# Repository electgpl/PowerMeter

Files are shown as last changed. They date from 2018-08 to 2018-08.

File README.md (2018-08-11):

# Power Meter v1 

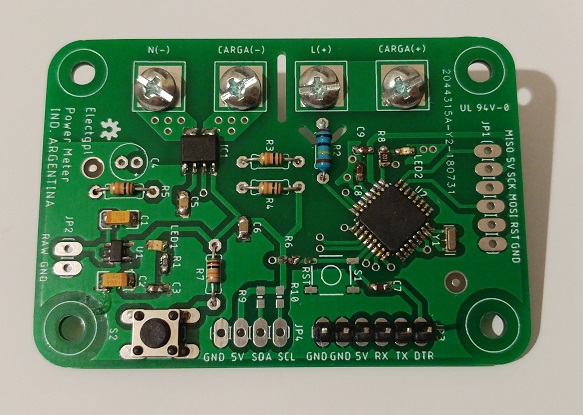
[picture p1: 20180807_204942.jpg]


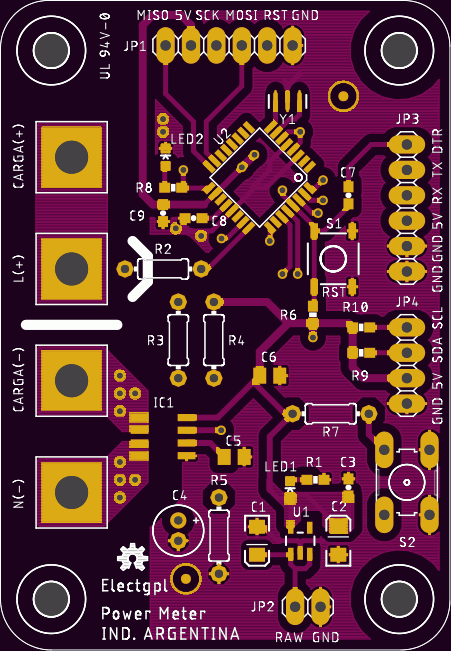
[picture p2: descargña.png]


Este es un medidor de potencia continua y alterna diseñado en base al microcontrolador AVR linea MEGA compatible ArduinoIDE.

  - Core AVR - **ARDUINO PRO MINI 5V**
  - Bootloader UART Arduino Compatible
  - ISP Compatible
  - Serial Terminal/Debug
  - Puerto para LCD I2C
  - Medidor de corriente ACS712 (Compatible 5, 20 y 30A) 
  - Medidor de Tensión **Directo** con atenuación resistiva y montado sobre 2.5V (Cero)
  - Fuente de alimentación integrada

## Lenguajes Compatibles

  - C
  - C++
  - Basic
  - Ensamblador
  - Ladder
  - y mas...
  
## Diseño y Desarrollo

> Diseñado en dos capas con SMD y THT
> Los componentes SMD son extraídos directamente de una placa Arduino Pro Mini 5V y Modulo ACS712
> Los componentes THT se adquieren con facilidad en los comercios.
>                           
> PCB creado en [JLCPCB].
> Diseño realizado en [Eagle].

### Instalación

Todos los archivos se encuentran disponibles en este repositorio, diagramas, pcb, etc...

### Pendientes

 - Código para el medidor de continua para la incorporación en fuentes de alimentación.
 - Mejoras en la aislación de seguridad eléctrica

License
----

MIT

**Free Software, Hell Yeah!**

[JLCPCB]: <https://jlcpcb.com/>
[Eagle]: <https://www.autodesk.com/products/eagle/overview>

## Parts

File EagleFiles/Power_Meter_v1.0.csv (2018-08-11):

Qty | Value | Device | Package | Parts | Description | MF | MPN | OC_FARNELL | OC_NEWARK | SPICEPREFIX
1 |  | 10-XX | B3F-10XX | S2 | OMRON SWITCH |  | B3F-1000 | 176432 | 36M3542
1 |  | PINHD-1X2 | 1X02 | JP2 | PIN HEADER
1 |  | PINHD-1X4 | 1X04 | JP4 | PIN HEADER
2 |  | PINHD-1X6 | 1X06 | JP1, JP3 | PIN HEADER
2 |  | RESISTOR0603-RES | 0603-RES | R9, R10 | Resistor
4 | 0.1uF | CAP0603-CAP | 0603-CAP | C3, C7, C8, C9 | Capacitor
1 | 100n | C-EUC0805K | C0805K | C6 | CAPACITOR, European symbol |  |  |  |  | C
2 | 10K | RESISTOR0603-RES | 0603-RES | R1, R6 | Resistor
4 | 10k | R-US_0204/7 | 0204/7 | R3, R4, R5, R7 | RESISTOR, American symbol |  |  |  |  | R
2 | 10uF | CAP_POL1206 | EIA3216 | C1, C2 | Capacitor Polarized
1 | 1M | R-US_0204/7 | 0204/7 | R2 | RESISTOR, American symbol |  |  |  |  | R
1 | 1n | C-EUC0805K | C0805K | C5 | CAPACITOR, European symbol |  |  |  |  | C
1 | 1u | CPOL-EUE2-5 | E2-5 | C4 | POLARIZED CAPACITOR, European symbol |  |  |  |  | C
1 | 330 | RESISTOR0603-RES | 0603-RES | R8 | Resistor
1 | 8/16/20MHz | RESONATOR1:1 | RESONATOR-SMD-1:1 | Y1 | Resonator
1 | ACS712 | ACS712 | SO08 | IC1
1 | ATMEGA328 | ATMEGA168 | TQFP32-08 | U2
2 | FIDUCIAL1X2.5 | FIDUCIAL1X2.5 | FIDUCIAL-1X2.5 | JP5, JP6 | Fiducial Alignment Points
1 | Green | LED | 0603-LED-ALT1 | LED2 | LEDs
1 | MIC5205 | V_REG_LDOSMD | SOT23-5 | U1 | Voltage Regulator LDO
4 | MOUNT-PAD-SQUARE3.3 | MOUNT-PAD-SQUARE3.3 | 3,3-PAD-SQUARE | H1, H2, H3, H4 | MOUNTING PAD, square
1 | OSHW-LOGOS | OSHW-LOGOS | OSHW-LOGO-S | U$5 | Open Source Hardware Logo This logo indicates the piece of hardware it is found on incorporates a OSHW license and/or adheres to the definition of open source hardware found here: http://freedomdefined.org/OSHW
1 | Red | LED | 0603-LED-ALT1 | LED1 | LEDs
1 | Reset | SWITCH-MOMENTARY-2SMD-ALT01 | TACTILE-SWITCH-SMD-ALT01 | S1 | Various NO switches- pushbuttons, reed, etc

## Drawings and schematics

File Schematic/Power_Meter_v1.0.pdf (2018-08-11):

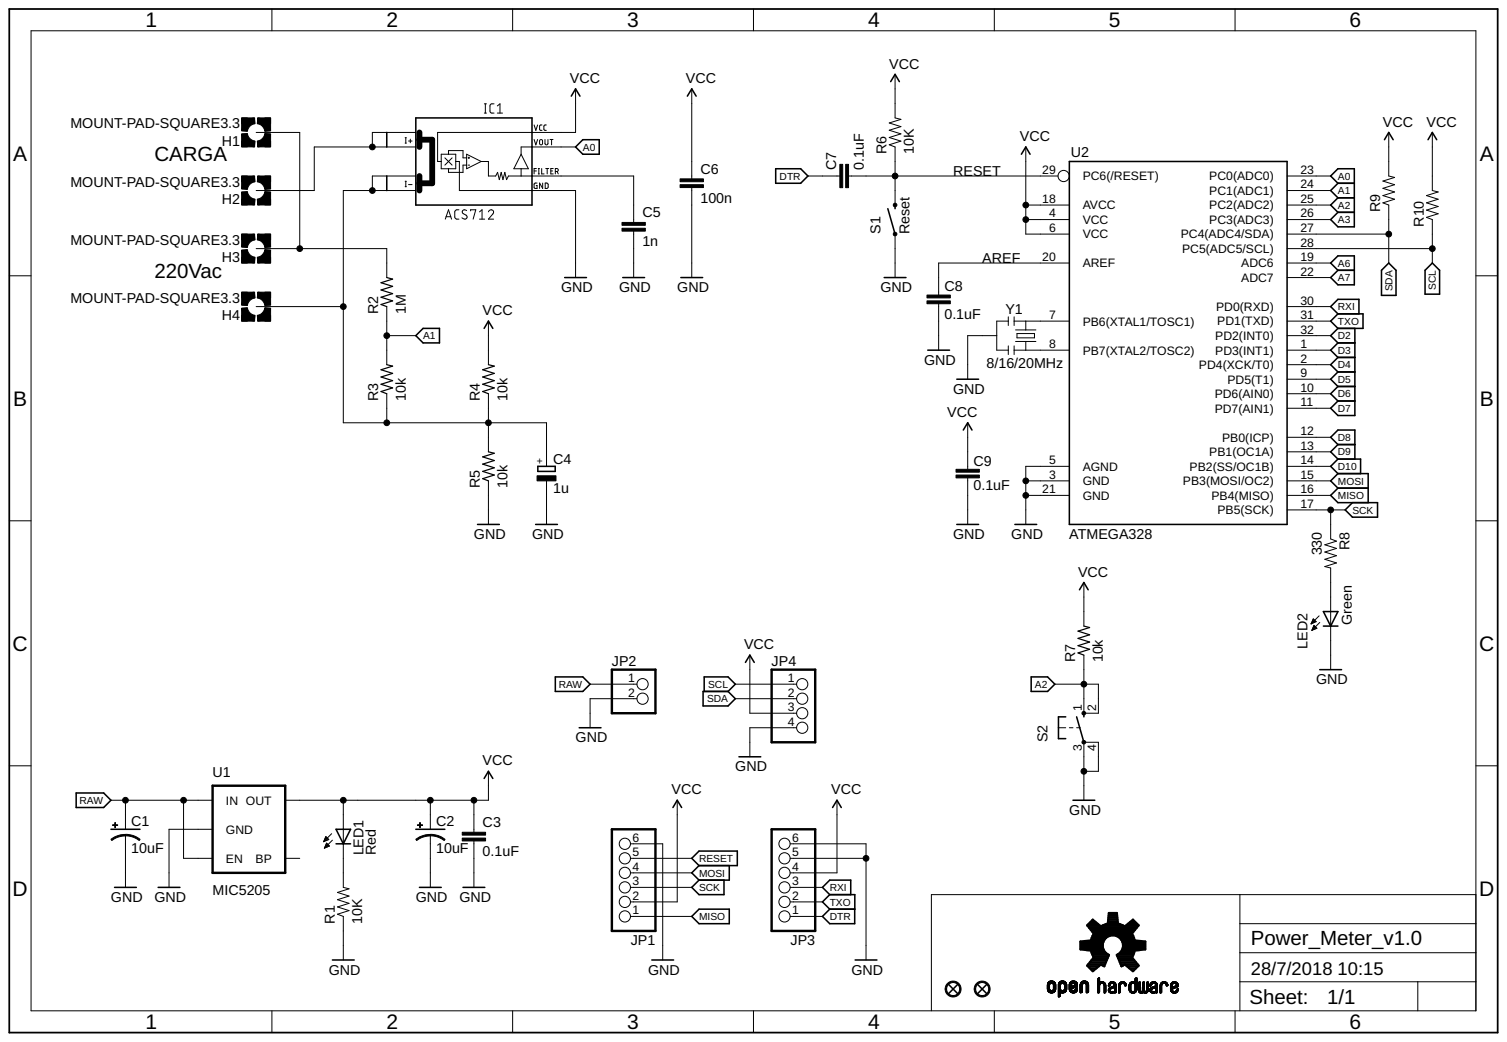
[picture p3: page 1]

VCC

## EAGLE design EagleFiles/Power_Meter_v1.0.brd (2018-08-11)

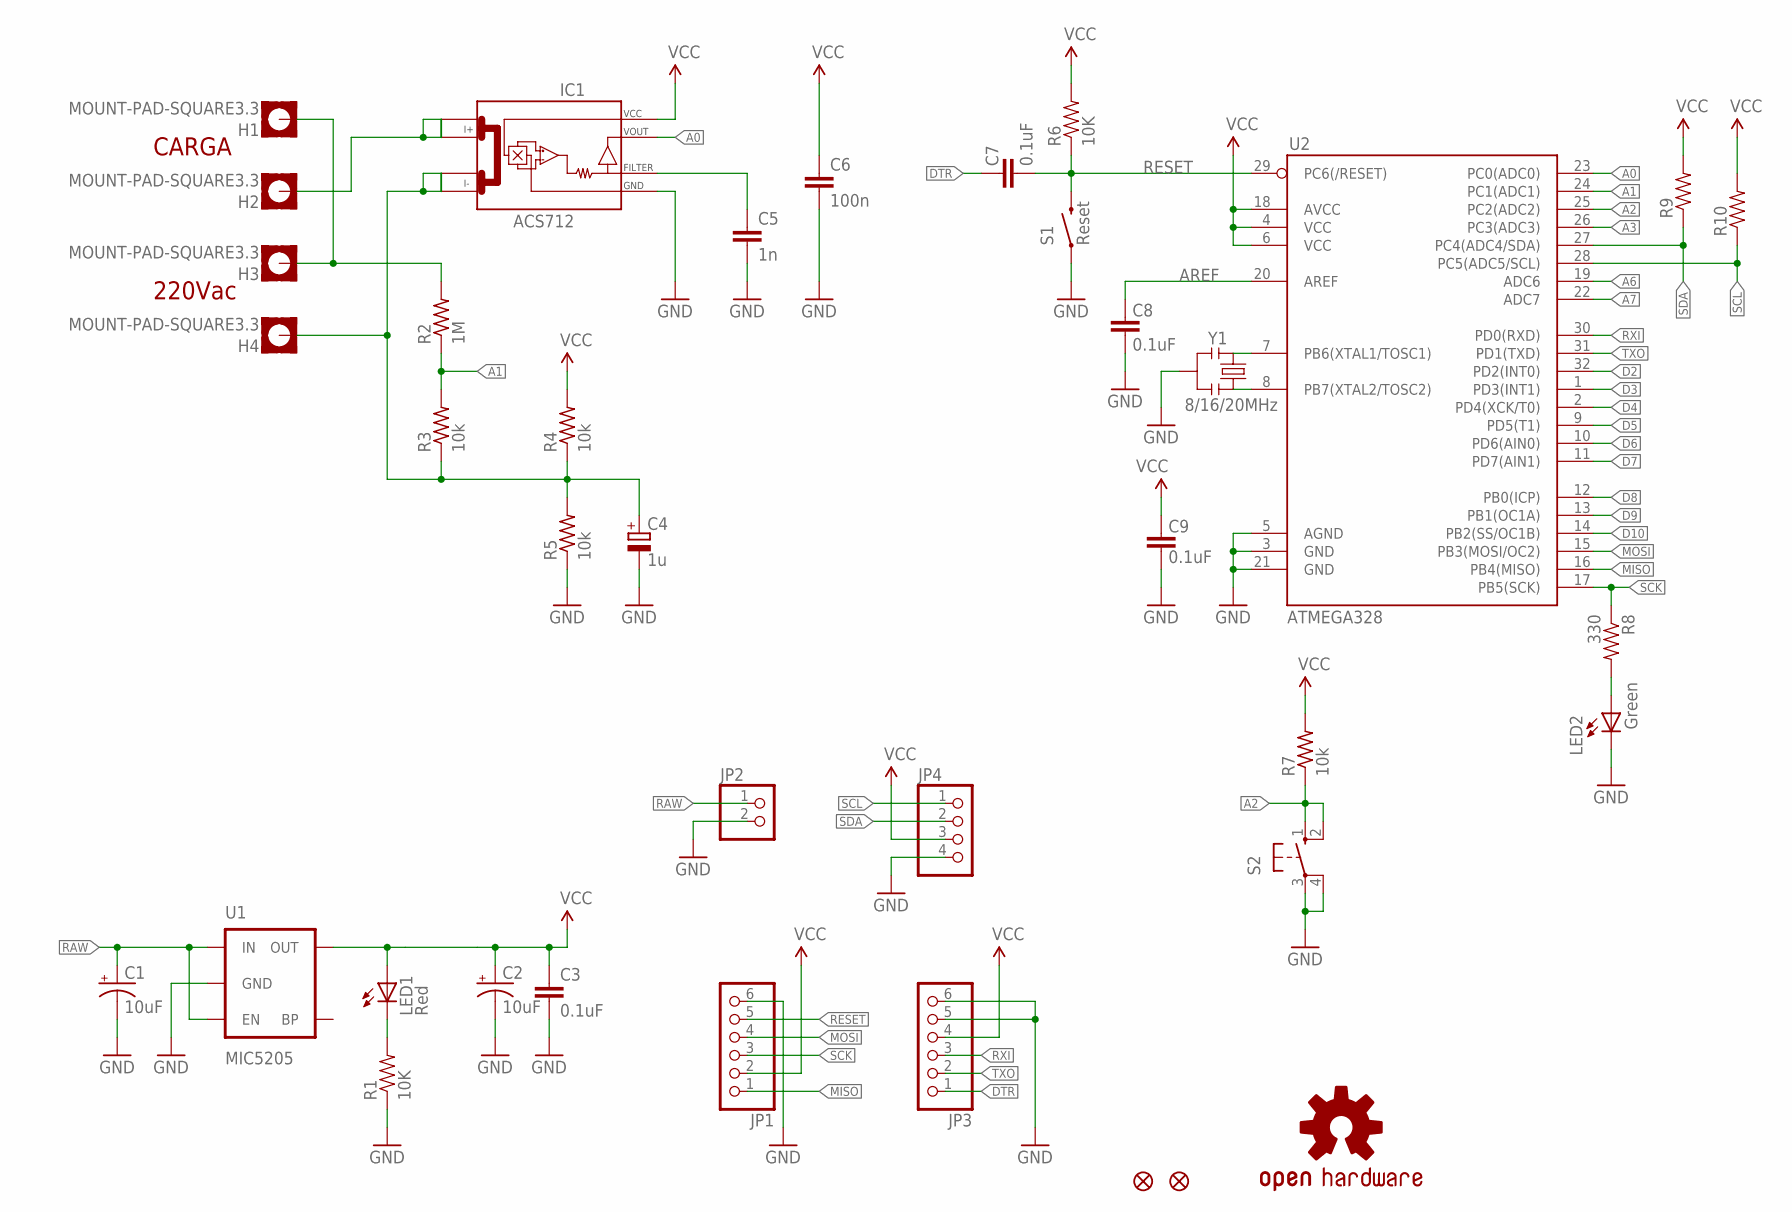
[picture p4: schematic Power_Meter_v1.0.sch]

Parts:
C1, C2: 10uF; EIA3216
C3, C7, C8, C9: 0.1uF; 0603-CAP
C4: 1u; E2-5
C5: 1n; C0805K
C6: 100n; C0805K
H1, H2, H3, H4: MOUNT-PAD-SQUARE3.3; 3,3-PAD-SQUARE
IC1: ACS712; SO08
JP1, JP3: PINHD-1X6; 1X06
JP2: PINHD-1X2; 1X02
JP4: PINHD-1X4; 1X04
JP5, JP6: FIDUCIAL1X2.5; FIDUCIAL-1X2.5
LED1: Red; 0603-LED-ALT1
LED2: Green; 0603-LED-ALT1
R1, R6: 10K; 0603-RES
R2: 1M; 0204/7
R3, R4, R5, R7: 10k; 0204/7
R8: 330; 0603-RES
R9, R10: RESISTOR0603-RES; 0603-RES
S1: Reset; TACTILE-SWITCH-SMD-ALT01
S2: 10-XX; B3F-10XX
U1: MIC5205; SOT23-5
U2: ATMEGA328; TQFP32-08
U$5: OSHW-LOGOS; OSHW-LOGO-S
Y1: 8/16/20MHz; RESONATOR-SMD-1:1

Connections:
A0: IC1.7 (VOUT), U2.23 (PC0(ADC0))
A1: R2.1, R3.2, U2.24 (PC1(ADC1))
A2: R7.1, S2.1 (S), S2.2 (S1), U2.25 (PC2(ADC2))
A3: U2.26 (PC3(ADC3))
A6: U2.19 (ADC6)
A7: U2.22 (ADC7)
AREF: C8.2, U2.20 (AREF)
D2: U2.32 (PD2(INT0))
D3: U2.1 (PD3(INT1))
D4: U2.2 (PD4(XCK/T0))
D5: U2.9 (PD5(T1))
D6: U2.10 (PD6(AIN0))
D7: U2.11 (PD7(AIN1))
D8: U2.12 (PB0(ICP))
D9: U2.13 (PB1(OC1A))
D10: U2.14 (PB2(SS/OC1B))
DTR: C7.2, JP3.1
GND: C1.C (-), C2.C (-), C3.2, C4.-, C5.2, C6.2, C8.1, C9.1, IC1.5 (GND), JP1.6, JP2.2, JP3.5, JP3.6, JP4.4, LED2.C, R1.1, R5.1, S1.1, S1.2 (1), S2.3, S2.4 (P1), U1.2 (GND), U2.3 (GND), U2.5 (AGND), U2.21 (GND), Y1.2
MISO: JP1.1, U2.16 (PB4(MISO))
MOSI: JP1.4, U2.15 (PB3(MOSI/OC2))
unnamed: LED2.A, R8.2
unnamed: U2.8 (PB7(XTAL2/TOSC2)), Y1.3
unnamed: U2.7 (PB6(XTAL1/TOSC1)), Y1.1
unnamed: H1.B3,3, H3.B3,3, R2.2
unnamed: C5.1, IC1.6 (FILTER)
unnamed: H2.B3,3, IC1.1 (I+_0), IC1.2 (I+_1)
unnamed: LED1.C, R1.2
unnamed: C4.+, H4.B3,3, IC1.3 (I-_0), IC1.4 (I-_1), R3.1, R4.1, R5.2
RAW: C1.A (+), JP2.1, U1.1 (IN), U1.3 (EN)
RESET: C7.1, JP1.5, R6.1, S1.3 (2), S1.4 (2), U2.29 (PC6(/RESET))
RXI: JP3.3, U2.30 (PD0(RXD))
SCK: JP1.3, R8.1, U2.17 (PB5(SCK))
SCL: JP4.1, R10.1, U2.28 (PC5(ADC5/SCL))
SDA: JP4.2, R9.1, U2.27 (PC4(ADC4/SDA))
TXO: JP3.2, U2.31 (PD1(TXD))
VCC: C2.A (+), C3.1, C6.1, C9.2, IC1.8 (VCC), JP1.2, JP3.4, JP4.3, LED1.A, R4.2, R6.2, R7.2, R9.2, R10.2, U1.5 (OUT), U2.4 (VCC), U2.6 (VCC), U2.18 (AVCC)

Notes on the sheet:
CARGA
220Vac

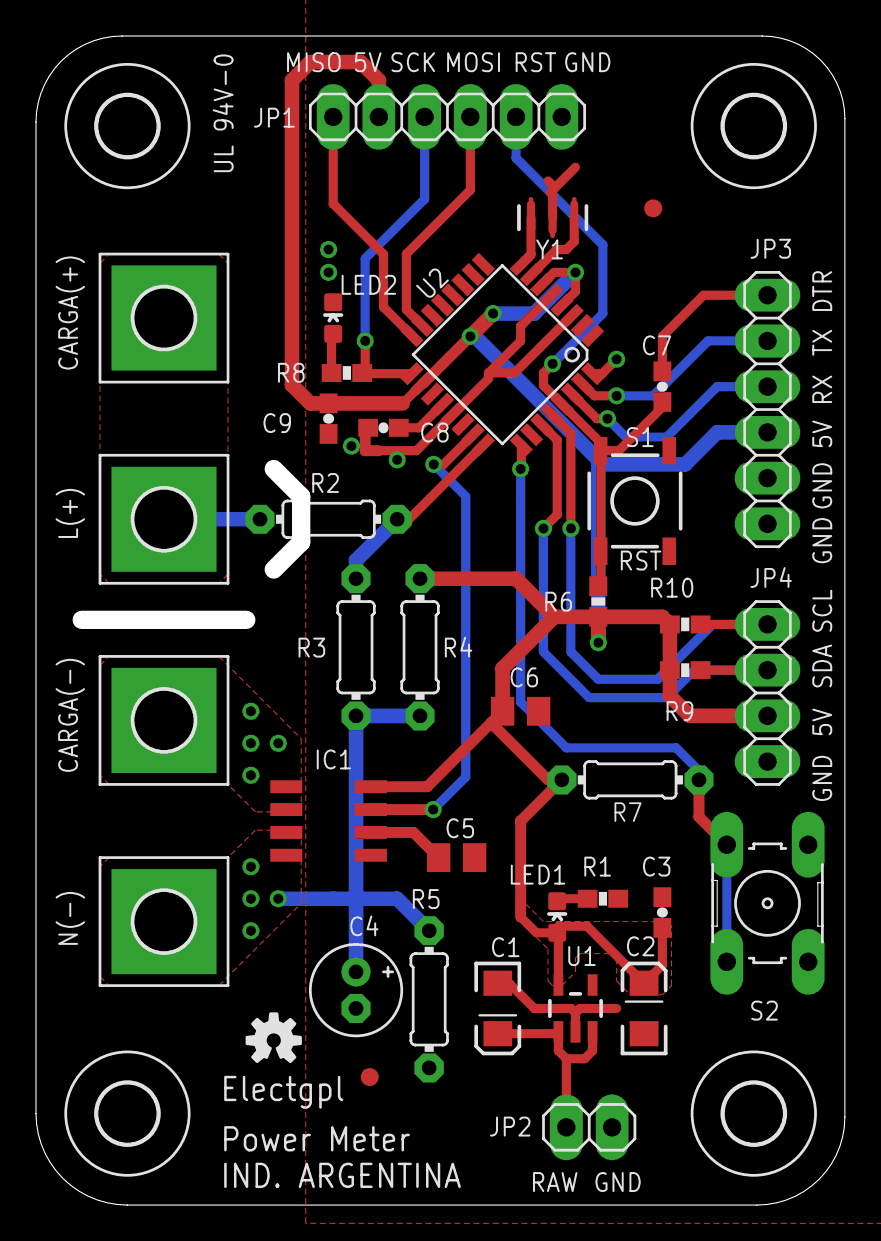
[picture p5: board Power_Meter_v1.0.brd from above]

Board: 2 copper layers, 44.9 x 64.9 mm, 42 parts (0 on the bottom side), 24 nets.

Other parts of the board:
U$1, U$2, U$3, U$4: 3,3

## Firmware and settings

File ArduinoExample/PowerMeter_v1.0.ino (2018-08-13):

#include <math.h>
#define CONST_CORRIENTE 5
#define CONST_TENSION   100
int i=0, adcZ=0; 
float ADCvRef=0;
float adc1=0, valorMax1=0, adc2=0, valorMax2=0;
float tension, corriente, potencia;
//-----------------------------------------------------------
//Funcion de calculo de tension de alimentacion
//-----------------------------------------------------------
int vRefADC(){
   long result;
   ADMUX = _BV(REFS0) | _BV(MUX3) | _BV(MUX2) | _BV(MUX1);
   delay(2);
   ADCSRA |= _BV(ADSC);
   while (bit_is_set(ADCSRA,ADSC));
   result = ADCL;
   result |= ADCH<<8;
   result = 1125300L / result;
   return result;
}
//-----------------------------------------------------------
//Funcion de configuracion
//-----------------------------------------------------------
void setup(){
   Serial.begin(9600);
   ADCvRef = vRefADC();
}
//-----------------------------------------------------------
//Funcion repetitiva
//-----------------------------------------------------------
void loop(){
   do{
      adcZ=analogRead(A1)-512;
      delayMicroseconds(20);
   }while(adcZ<10);
   for(i=0;i<50;i++){
      adc1=(analogRead(A1)*ADCvRef/1023.0)-2500;
      delayMicroseconds(33);
      valorMax1=adc1*adc1+valorMax1;
      adc2=(analogRead(A0)*ADCvRef/1023.0)-2500;
      delayMicroseconds(33);
      valorMax2=adc2*adc2+valorMax2;
   }  
   tension=(sqrt(valorMax1/50)*CONST_TENSION)/1000;
   corriente=(sqrt(valorMax2/50)*CONST_CORRIENTE)/1000;
   potencia=tension*corriente;
   delay(2000);
   potencia = tension * corriente; 
   Serial.print("V:");
   Serial.print(tension);
   Serial.print(" | ");
   Serial.print("A:");
   Serial.print(corriente);
   Serial.print(" | ");
   Serial.print("W:");
   Serial.println(potencia);
   Serial.println("");
   valorMax1=0;
   valorMax2=0;
}

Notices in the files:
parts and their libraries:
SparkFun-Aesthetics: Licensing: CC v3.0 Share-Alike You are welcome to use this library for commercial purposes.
